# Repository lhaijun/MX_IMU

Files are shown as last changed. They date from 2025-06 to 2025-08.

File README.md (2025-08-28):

1. 代码优化：更合理稳定的代码组织结构为了优化数据读取、姿态解算和串口发送的代码结构，同时提升稳定性和可维护性，建议从以下几个方面入手：1.1 任务划分与优先级设计目前你使用 FreeRTOS 的定时器轮询方式，虽然简单，但可能导致任务耦合过高，且实时性难以保证。建议将功能模块拆分为独立的任务，利用 FreeRTOS 的多任务特性来提升代码模块化和稳定性。任务拆分建议：IMU 数据读取任务（高优先级）：负责从 ICM42688P 读取原始数据（加速度、角速度等）。建议使用 SPI/I2C 中断驱动的方式，避免轮询占用 CPU。读取频率可以根据 IMU 的采样率（如 100Hz 或 200Hz）设置。
姿态解算任务（中优先级）：接收 IMU 原始数据，进行姿态解算（如四元数或欧拉角）。可以利用 FreeRTOS 的队列（Queue）或信号量（Semaphore）从 IMU 任务获取数据，避免直接调用。
数据发送任务（低优先级）：负责将解算结果通过串口（UART）以 MAVLink 协议发送到上位机。可以使用另一队列接收姿态解算任务的数据。
命令处理任务（低优先级）：处理上位机通过 MAVLink 协议发送的参数调整命令，更新板载配置。

优先级设置：IMU 读取任务优先级最高，确保数据采集的实时性。
姿态解算次之，保证解算的及时性。
数据发送和命令处理优先级较低，因为串口通信和参数调整对实时性要求较低。

任务通信：使用 FreeRTOS 的 队列（Queue） 传递数据，例如：IMU 任务将原始数据放入队列，姿态解算任务从中读取。
姿态解算任务将结果放入另一个队列，供数据发送任务使用。

如果需要同步，使用 信号量（Semaphore） 或 事件标志（Event Group） 通知任务间状态。

1.2 替换定时器轮询为中断驱动IMU 数据读取：ICM42688P 支持数据就绪中断（Data Ready Interrupt）。建议配置中断引脚，当 IMU 数据准备好时触发中断，在中断服务函数（ISR）中读取数据并存入队列。这样可以避免轮询浪费 CPU 资源。
串口发送：使用 UART 的 DMA 模式发送 MAVLink 数据包，减少 CPU 干预。FreeRTOS 的任务只需将数据写入 DMA 缓冲区，硬件会自动完成发送。
姿态解算：姿态解算任务可以由事件触发（如队列中有新数据时运行），避免固定周期轮询。

1.3 代码模块化分离硬件驱动与应用逻辑：将 ICM42688P 的 SPI/I2C 驱动代码封装为独立模块（如 icm42688p.c/h），提供初始化、数据读取等接口。
姿态解算算法（如 Madgwick 或 Mahony 滤波）封装为单独模块（如 attitude.c/h），输入为 IMU 数据，输出为姿态数据。
MAVLink 协议处理封装为单独模块（如 mavlink_handler.c/h），负责打包和解析数据。

配置文件：将关键参数（如 IMU 采样率、滤波参数、串口波特率）集中在一个配置文件（如 config.h）中，方便上位机调整和代码维护。
错误处理：为每个模块添加错误检测和日志记录（如通过串口输出调试信息），便于调试和排查问题。

1.4 优化 FreeRTOS 资源使用任务栈大小：使用 FreeRTOS 的 uxTaskGetStackHighWaterMark 检查每个任务的栈使用情况，调整栈大小以节省内存。
队列长度：根据数据速率和任务调度频率，合理设置队列长度，避免队列满导致数据丢失。
调度器优化：确保任务调度频率与硬件性能匹配，避免任务抢占导致延迟。例如，IMU 采样率 100Hz，任务调度周期应与之同步。

1.5 示例代码结构以下是一个推荐的 FreeRTOS 任务组织示例：c

#include "FreeRTOS.h"
#include "task.h"
#include "queue.h"
#include "icm42688p.h"
#include "attitude.h"
#include "mavlink_handler.h"

// 队列句柄
QueueHandle_t imu_data_queue, attitude_data_queue;

// IMU 数据读取任务
void imu_read_task(void *pvParameters) {
    while (1) {
        // 假设通过中断触发读取
        imu_data_t data = icm42688p_read();
        xQueueSend(imu_data_queue, &data, portMAX_DELAY);
        vTaskDelay(pdMS_TO_TICKS(10)); // 100Hz
    }
}

// 姿态解算任务
void attitude_task(void *pvParameters) {
    imu_data_t imu_data;
    attitude_data_t attitude;
    while (1) {
        if (xQueueReceive(imu_data_queue, &imu_data, portMAX_DELAY)) {
            attitude = attitude_calculate(&imu_data);
            xQueueSend(attitude_data_queue, &attitude, portMAX_DELAY);
        }
    }
}

// 数据发送任务
void mavlink_send_task(void *pvParameters) {
    attitude_data_t attitude;
    while (1) {
        if (xQueueReceive(attitude_data_queue, &attitude, portMAX_DELAY)) {
            mavlink_send_attitude(&attitude);
        }
    }
}

void main(void) {
    // 初始化硬件和 FreeRTOS
    icm42688p_init();
    mavlink_init();
    
    // 创建队列
    imu_data_queue = xQueueCreate(10, sizeof(imu_data_t));
    attitude_data_queue = xQueueCreate(10, sizeof(attitude_data_t));
    
    // 创建任务
    xTaskCreate(imu_read_task, "IMU", 256, NULL, 3, NULL);
    xTaskCreate(attitude_task, "Attitude", 512, NULL, 2, NULL);
    xTaskCreate(mavlink_send_task, "MAVLink", 256, NULL, 1, NULL);
    
    // 启动调度器
    vTaskStartScheduler();
}

1.6 性能测试与验证实时性测试：使用逻辑分析仪或调试串口记录任务执行时间，确保 IMU 数据读取和姿态解算满足实时性要求。
稳定性测试：长时间运行系统，检查是否有内存泄漏或任务死锁。
数据一致性：验证上位机接收的 MAVLink 数据与板载解算结果一致。

2. 开源文档组织：GitHub 开源准备为了在 GitHub 上开源你的设计和代码，清晰的文档和项目结构是吸引用户和贡献者的关键。以下是建议的文档组织方式和内容：2.1 仓库结构

project_name/
├── docs/                     # 文档目录
│   ├── hardware/             # 硬件相关文档
│   ├── software/             # 软件相关文档
│   └── tutorials/            # 使用教程
├── firmware/                 # 固件代码
│   ├── src/                  # 源代码
│   ├── inc/                  # 头文件
│   └── lib/                  # 第三方库（如 FreeRTOS、MAVLink）
├── hardware/                 # 硬件设计文件
│   ├── schematic/            # 原理图（如 KiCad 文件）
│   ├── pcb/                  # PCB 布局
│   └── bom/                  # 物料清单
├── examples/                 # 示例代码或上位机代码
├── LICENSE                   # 开源许可证（如 MIT、Apache 2.0）
└── README.md                 # 项目主页

2.2 README.md 内容README 是项目的门面，需简洁但信息全面。建议包含以下内容：项目概述：简要介绍项目（STM32F405 + ICM42688P 的 IMU 系统，支持 MAVLink 协议）。
功能特性：IMU 数据读取（加速度、角速度）
姿态解算（四元数/欧拉角）
MAVLink 协议通信
FreeRTOS 实时系统

硬件要求：列出核心硬件（STM32F405、ICM42688P）及其连接方式。
软件依赖：STM32CubeIDE 或其他 IDE
FreeRTOS
MAVLink 库

快速开始：克隆仓库：git clone <repo_url>
硬件连接说明
编译和烧录固件步骤
上位机配置和运行

贡献指南：如何提交 Issue 或 Pull Request。
许可证：明确项目的开源许可证。
联系方式：可选，提供邮箱或社区链接。

2.3 文档内容硬件文档（docs/hardware/）：原理图和 PCB 设计说明（推荐使用 KiCad 或 Eagle）。
物料清单（BOM），包括元件型号和供应商链接。
硬件连接说明（如 SPI/I2C 引脚分配）。

软件文档（docs/software/）：代码架构说明（任务划分、模块功能）。
MAVLink 协议实现细节（支持的消息类型、参数调整流程）。
姿态解算算法说明（如 Madgwick 滤波的原理和参数）。

使用教程（docs/tutorials/）：固件烧录教程（使用 ST-Link 或其他工具）。
上位机配置和运行说明。
参数调整示例（如通过 MAVLink 修改滤波增益）。

API 文档（可选）：如果代码模块化程度高，可使用 Doxygen 生成 API 文档。

2.4 开源注意事项选择许可证：推荐 MIT 或 Apache 2.0，简单且适合硬件/软件开源。确保在仓库根目录添加 LICENSE 文件。
代码注释：确保代码有清晰的注释，尤其是关键模块（如 IMU 驱动、姿态解算）。
版本管理：使用 Git 提交规范（如 feat: add IMU driver），并定期发布版本（Releases）。
测试用例：提供简单的测试代码或脚本，帮助用户验证硬件和固件功能。
社区互动：在 README 中添加 GitHub Issues 模板，鼓励用户反馈问题或贡献代码。

2.5 示例 README 片段markdown

# STM32F405 + ICM42688P IMU Project

A FreeRTOS-based IMU system using STM32F405 and ICM42688P, with MAVLink protocol support for attitude calculation and data communication.

## Features
- High-frequency IMU data acquisition (100Hz+)
- Real-time attitude calculation (quaternion/Euler angles)
- MAVLink protocol for PC communication
- Configurable parameters via MAVLink

## Getting Started
1. Clone the repository:
   ```bash
   git clone https://github.com/yourusername/project_name

Connect STM32F405 and ICM42688P via SPI/I2C (see docs/hardware/).
Build and flash firmware using STM32CubeIDE.
Run the provided PC application to receive MAVLink data.

LicenseMIT License

---

### 3. 其他建议
- **硬件优化**：
  - 检查 ICM42688P 的电源和信号完整性，确保数据读取稳定。
  - 如果可能，添加外部晶振以提高 STM32F405 的时钟精度。
- **上位机完善**：
  - 在上位机中添加数据可视化功能（如姿态 3D 模型）。
  - 提供 MAVLink 参数调整的 GUI 界面，方便用户操作。
- **开源社区推广**：
  - 在 X 或其他技术社区分享你的项目，吸引开发者参与。
  - 考虑制作一个简单的演示视频，展示硬件运行效果。

---

### 总结
- **代码优化**：将功能拆分为 FreeRTOS 任务（IMU 读取、姿态解算、数据发送），使用中断驱动和队列通信，模块化代码结构。
- **文档组织**：在 GitHub 上创建清晰的目录结构，编写详细的 README 和模块化文档，选择合适的许可证。

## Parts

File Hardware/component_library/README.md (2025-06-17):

# component_library

KiCad component library.

---

<details markdown="1">
  <summary>Table of Contents</summary>

<!-- TOC -->
* [component_library](#componentlibrary)
  * [1 Overview](#1-overview)
  * [2 Symbol Conventions](#2-symbol-conventions)
    * [2.1 General Properties](#21-general-properties)
    * [2.2 Simulation Model](#22-simulation-model)
  * [3 Footprint Conventions](#3-footprint-conventions)
    * [3.1 General Properties](#31-general-properties)
    * [3.2 Clearance Overrides and Settings](#32-clearance-overrides-and-settings)
    * [3.3 3D Models](#33-3d-models)
  * [4 Automations (GitHub Actions)](#4-automations-github-actions)
<!-- TOC -->

</details>

---

## 1 Overview

This repo stores all KiCad component related files (symbols, footprints, 3d
models, etc.). Conventions are listed below.

---

## 2 Symbol Conventions

### 2.1 General Properties

| n  | Name | Explained | Show | KiCad Default |
|----|---|---|---|---|
| 1  | `Reference` | Symbol reference (REQUIRED)  | Yes  | Yes |
| 2  | `Value` | Value, if applicable | Yes  | Yes |
| 3  | `Footprint` | Location from repo root dir  | No | Yes |
| 4  | `Datasheet` | URL/location of datasheet | No | Yes |
| 5  | `Description` | Short 1 sentence description | No | Yes |
| 6  | `Manufacturer` | Fab/manufacturer name | No | No |
| 7  | `Manufacturer Part Number` | Must match if added! | No | No |
| 8  | `Distributor` | Supplier/distributor name | No | No |
| 9  | `Distributor Part Number`  | Must match if added! | No | No |
| 10 | `Distributor Link` | URL to product purchase page | No | No |

### 2.2 Simulation Model

Add simulation SPICE models for reasonable components as needed. Complete when
the benefit of an accurate SPICE model outweighs the required effort.

---

## 3 Footprint Conventions

### 3.1 General Properties

| n | Name | Explained | Show | Layer | KiCad Default |
|---|---|---|---|---|---|
| 1 | `Reference` | Footprint reference (REQUIRED) | Yes  | F.Silkscreen | Yes |
| 2 | `Value` | Value, if applicable | Yes  | F.Fab | Yes |
| 3 | `Footprint` | Location from repo root dir | No | No show | Yes |
| 4 | `Datasheet` | URL/location of datasheet | No | No show | Yes |
| 5 | `Description` | Short 1 sentence description | No | No show | Yes |
| 6 | `Manufacturer` | Fab/manufacturer name | No | No show | No |
| 7 | `Manufacturer Part Number` | Must match if added! | No | No show | No |

### 3.2 Clearance Overrides and Settings

All optional, follow manufacturer recommendations.

### 3.3 3D Models

Always add a module unless there is none (PCB only footprint).

---

## 4 Automations (GitHub Actions)

GitHub actions pipelines are used to verify component information and supply
chain using distributor APIs.

The following distributors are currently supported:

1. DigiKey
2. Mouser

Distributor API supply chain checker workflows are saved
in [distributor_apis](docs/workflows/distributor_apis) for reference.

- Discontinued due to limited development and unnecessary slowdown in the
  current development process.

The badge markdown would be as follows:

```
![black_formatter](https://github.com/danielljeon/component_library/actions/workflows/black_formatter.yaml/badge.svg)
![distributor_apis](https://github.com/danielljeon/component_library/actions/workflows/distributor_apis.yaml/badge.svg)
```

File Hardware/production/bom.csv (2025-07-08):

Designator | Footprint | Quantity | Value | LCSC Part #
C1 | 0402 | 1 | 0.1u
C10 | 0402 | 1 | 10n
C2, C201, C202, C203, C204, C205, C400 | 0402 | 7 | 100n | C1525
C200 | 0603 | 1 | 4u7 | C19666
C206 | 0402 | 1 | 1u | C52923
C207 | 0402 | 1 | 10n | C15195
C208, C209, C4, C5 | 0603 | 4 | 2u2 | C23630
C210, C211 | 0402 | 2 | 12p | C1547
C3 | 0603 | 1 | 1u
C31 | 0603 | 1 | 4n7
D3, D4, D5 | 0402 | 3 | LED
FB200 | 0805 | 1 | 600 @ 600 MHz | C1017
J1, J2 | PinHeader_1x04_P1.27mm_Vertical | 2 | KH-1.27PH180-1X4P-L7.2
J3 | molex_2171750001_usb_c_6p | 1 | 2171750001
J4 | CONN-HEADER-VERT-5POS-2.54MM | 1 | ZX-PZ2.54-1-5PZZ
R1, R2 | 0603 | 2 | 5k1
R13, R14, R29 | 0402 | 3 | 330R
R19, R20 | 0603 | 2 | 60R
R200 | 0402 | 1 | 47 | C25118
R203 | 0402 | 1 | 10k | C25744
R23, R24 | 0805 | 2 | 1k5
R400, R401, R403, R406, R407 | 0402 | 5 | 22 | C25092
R9 | 0603 | 1 | 10k
SW1 | SW_SPST_B3U-3000P-B | 1 | SW_SPST
U1 | to-252-2_dpak-2-leg | 1 | ld39150dt33-r
U2 | PQFN50P300X250X97-14N | 1 | ICM-42688-P
U200 | LQFP-64_10x10mm_P0.5mm | 1 | STM32F405RGT6 | C15742
U4 | SOIC-8_3.9x4.9mm_P1.27mm | 1 | AT24C256 | C6482
U6 | sot96-1_soic-8 | 1 | TJA1051T/3
Y200 | Crystal_SMD_3225-4Pin_3.2x2.5mm | 1 | 16MHz | C13738

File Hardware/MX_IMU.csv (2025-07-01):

Reference | Qty | Value | DNP | Exclude from BOM | Exclude from Board | Footprint | Datasheet
C1 | 1 | 0.1u |  |  |  | Capacitor_SMD:C_0402_1005Metric | ~
C3 | 1 | 1u |  |  |  | Capacitor_SMD:C_0603_1608Metric | ~
C4,C7,C208,C209 | 4 | 2u2 |  |  |  | Capacitor_SMD:C_0603_1608Metric | ~
C10 | 1 | 10n |  |  |  | Capacitor_SMD:C_0201_0603Metric | ~
C29 | 1 | 100n |  |  |  | Capacitor_SMD:C_0603_1608Metric | ~
C31 | 1 | 4n7 |  |  |  | Capacitor_SMD:C_0603_1608Metric | ~
C200 | 1 | 4u7 |  |  |  | Capacitor_SMD:C_0603_1608Metric | ~
C201,C202,C203,C204,C205,C400 | 6 | 100n |  |  |  | Capacitor_SMD:C_0402_1005Metric | ~
C206 | 1 | 1u |  |  |  | Capacitor_SMD:C_0402_1005Metric | ~
C207 | 1 | 10n |  |  |  | Capacitor_SMD:C_0402_1005Metric | ~
C210,C211 | 2 | 12p |  |  |  | Capacitor_SMD:C_0402_1005Metric | ~
D3,D4,D5 | 3 | LED |  |  |  | LED_SMD:LED_0402_1005Metric | ~
FB200 | 1 | 600 @ 600 MHz |  |  |  | Inductor_SMD:L_0805_2012Metric | ~
J1 | 1 | CAN |  |  |  | Connector_PinHeader_1.00mm:PinHeader_1x04_P1.00mm_Vertical_SMD_Pin1Right | ~
J2 | 1 | USART |  |  |  | Connector_PinHeader_1.00mm:PinHeader_1x04_P1.00mm_Vertical_SMD_Pin1Right | ~
J3 | 1 | 2171750001 |  |  |  | common:molex_2171750001_usb_c_6p | https://www.molex.com/en-us/products/part-detail/2171750001
J401 | 1 | SWD |  |  |  | Connector_PinHeader_1.27mm:PinHeader_2x05_P1.27mm_Vertical_SMD | ~
R1,R2 | 2 | 5k1 |  |  |  | Resistor_SMD:R_0603_1608Metric | ~
R9 | 1 | 10k |  |  |  | Resistor_SMD:R_0603_1608Metric | ~
R13,R14,R29 | 3 | 330R |  |  |  | Resistor_SMD:R_0402_1005Metric | ~
R19,R20 | 2 | 60R |  |  |  | Resistor_SMD:R_0603_1608Metric | ~
R23,R24 | 2 | 1k5 |  |  |  | Resistor_SMD:R_0805_2012Metric_Pad1.20x1.40mm_HandSolder | ~
R200 | 1 | 47 |  |  |  | Resistor_SMD:R_0402_1005Metric | ~
R203 | 1 | 10k |  |  |  | Resistor_SMD:R_0402_1005Metric | ~
R400,R401,R402,R403,R406,R407 | 6 | 22 |  |  |  | Resistor_SMD:R_0402_1005Metric | ~
SW1 | 1 | SW_SPST |  |  |  | Button_Switch_SMD:SW_SPST_B3U-3000P-B | ~
U1 | 1 | ld39150dt33-r |  |  |  | common:to-252-2_dpak-2-leg | https://www.st.com/resource/en/datasheet/ld39150.pdf
U2 | 1 | ICM-42688-P |  |  |  | ICM_42688_P:PQFN50P300X250X97-14N
U4 | 1 | AT24C256 |  |  |  | Package_SO:SOIC-8_3.9x4.9mm_P1.27mm | https://datasheet.lcsc.com/lcsc/2304140030_Microchip-Tech-AT24C256C-SSHL-T_C6482.pdf
U6 | 1 | TJA1051T/3 |  |  |  | nxp:sot96-1_soic-8 | https://www.nxp.com/docs/en/data-sheet/TJA1051.pdf
U200 | 1 | STM32F405RGT6 |  |  |  | Package_QFP:LQFP-64_10x10mm_P0.5mm | http://www.st.com/st-web-ui/static/active/en/resource/technical/document/datasheet/DM00037051.pdf
Y200 | 1 | 16MHz |  |  |  | Crystal:Crystal_SMD_3225-4Pin_3.2x2.5mm | ~

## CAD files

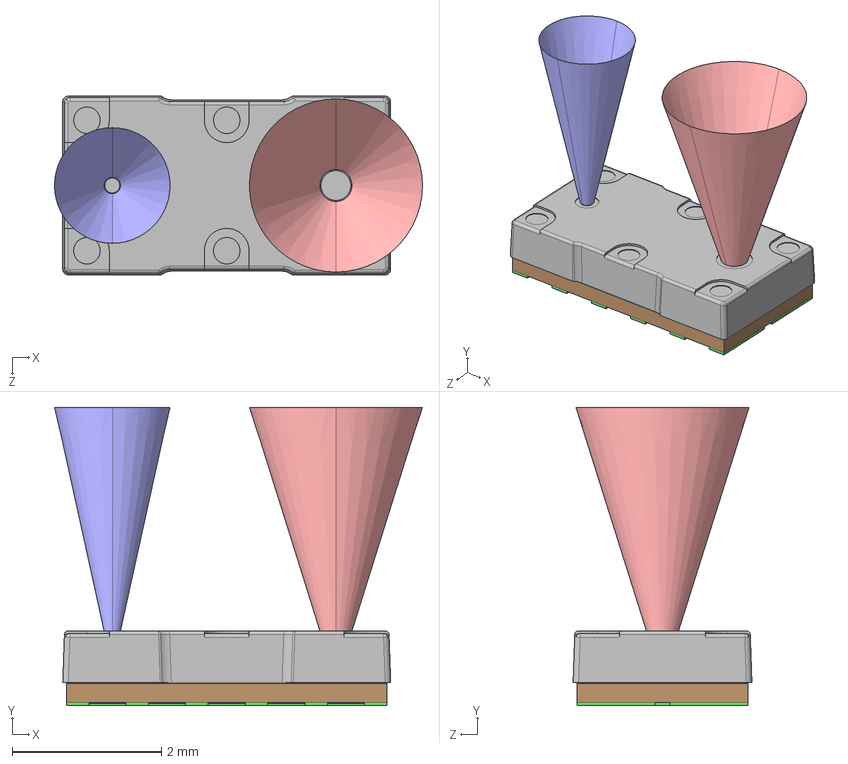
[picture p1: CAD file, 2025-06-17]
Hardware/component_library/model_3d/time_of_flight/VL53L3 MODULE ASSEMBLY.step
4.94 x 4.00 x 2.40 mm
VL53L3 Substrate
VL53L3 Cap
VL53L3 Tx Exclusion Cone
VL53L3 Rx Exclusion Cone

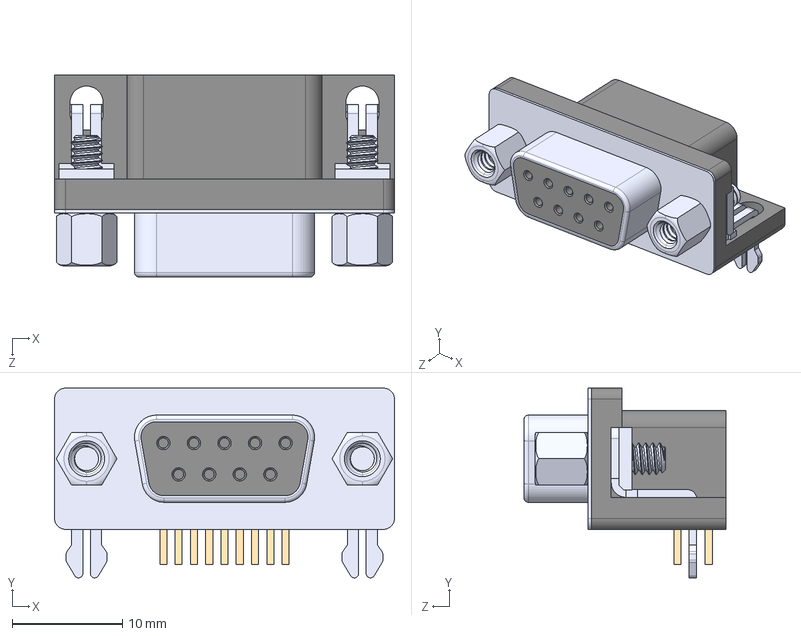
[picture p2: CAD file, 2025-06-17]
Hardware/component_library/A_DF_09_A_KG_T2S/A-DF_09_A_KG-T2S.step
30.8 x 17.2 x 18.3 mm

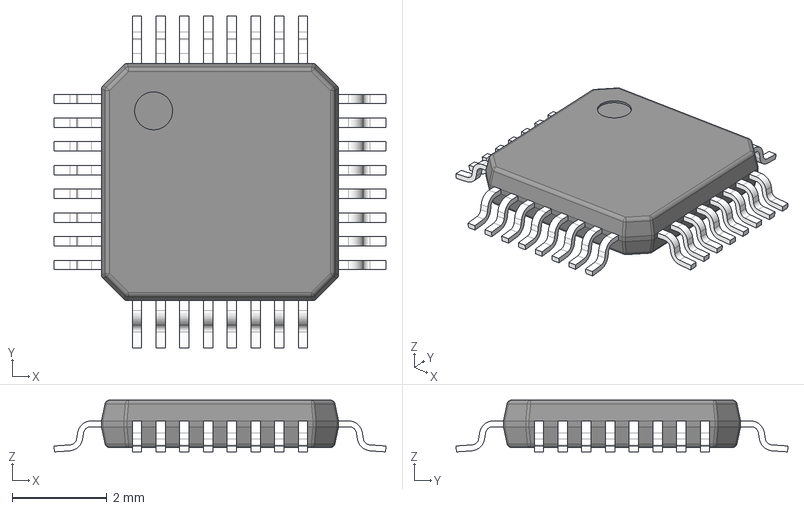
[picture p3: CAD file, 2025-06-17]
Hardware/component_library/model_3d/0_standard/TQFP-32.stp
7.00 x 7.00 x 1.09 mm
BODY-TQFP
LEAD-TQFP x 32
PIN1

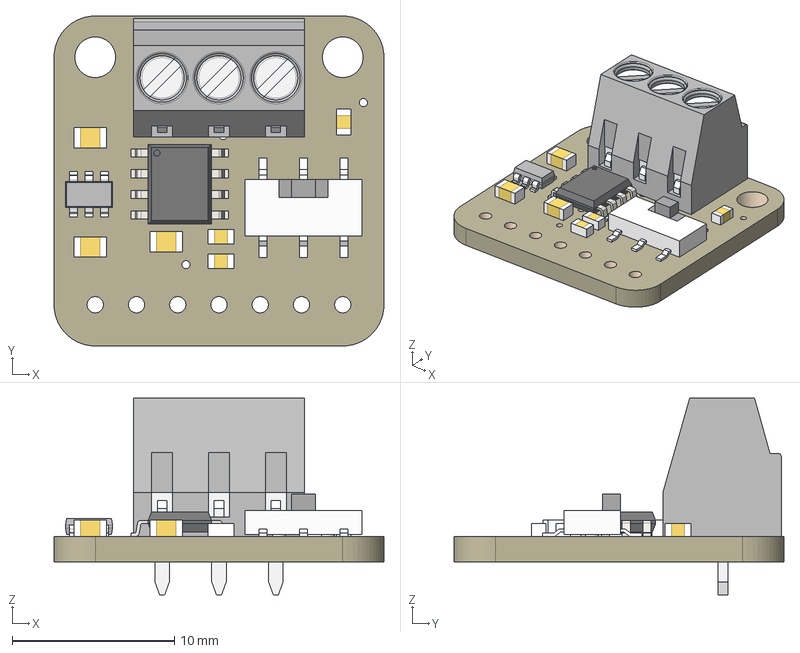
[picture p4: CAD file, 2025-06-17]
Hardware/component_library/model_3d/adafruit/5708 CAN Pal.step
20.3 x 20.3 x 12.1 mm
Board
TJA1051T/3
3.5mm Terminal
10uF x 2
AP3602
1uF
60 ohm x 3
EG1390

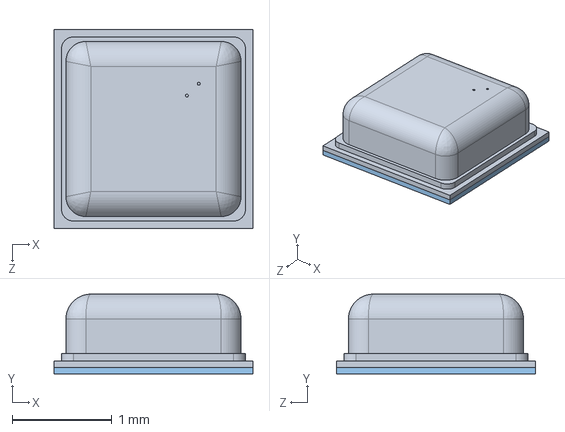
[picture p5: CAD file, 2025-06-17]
Hardware/component_library/model_3d/bosch/BMP581.step
2.00 x 0.801 x 2.00 mm

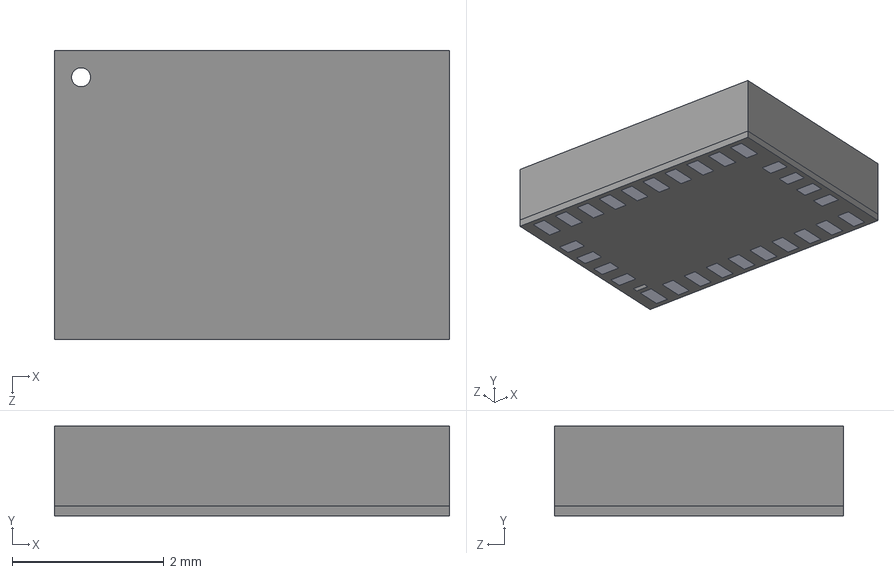
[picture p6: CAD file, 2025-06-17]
Hardware/component_library/model_3d/ceva/BNO085.stp
5.20 x 1.18 x 3.80 mm

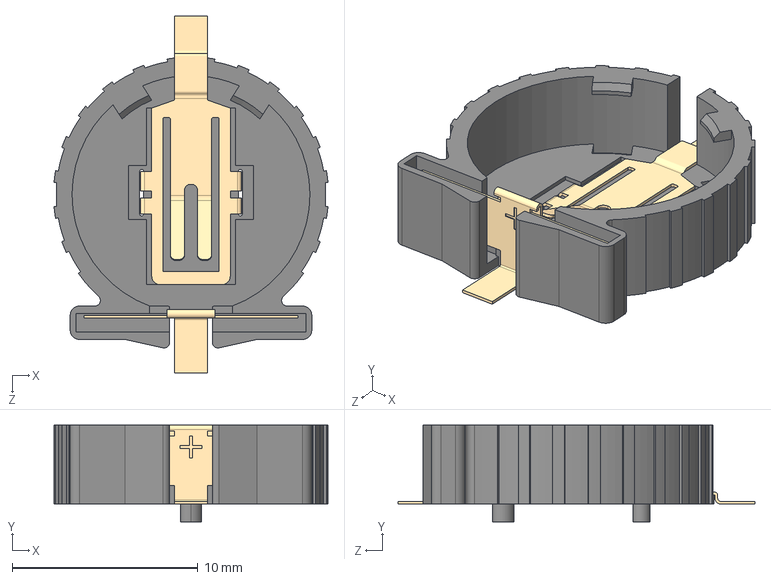
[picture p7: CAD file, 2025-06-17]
Hardware/component_library/model_3d/common/S8411-45R.step
14.7 x 5.20 x 19.2 mm

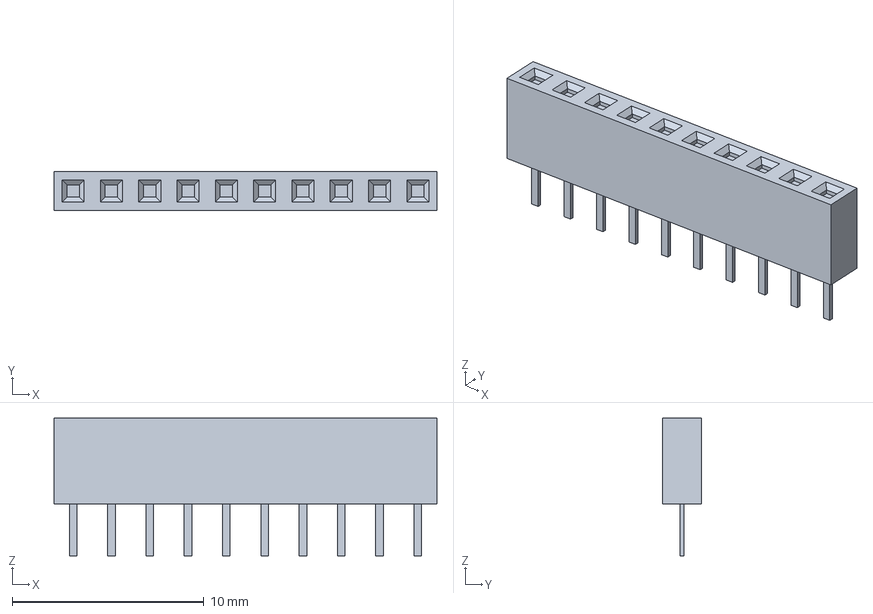
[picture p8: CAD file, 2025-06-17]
Hardware/component_library/model_3d/digi_xbee/c-1-2314876-0-a-3d.stp
20.0 x 2.06 x 7.20 mm

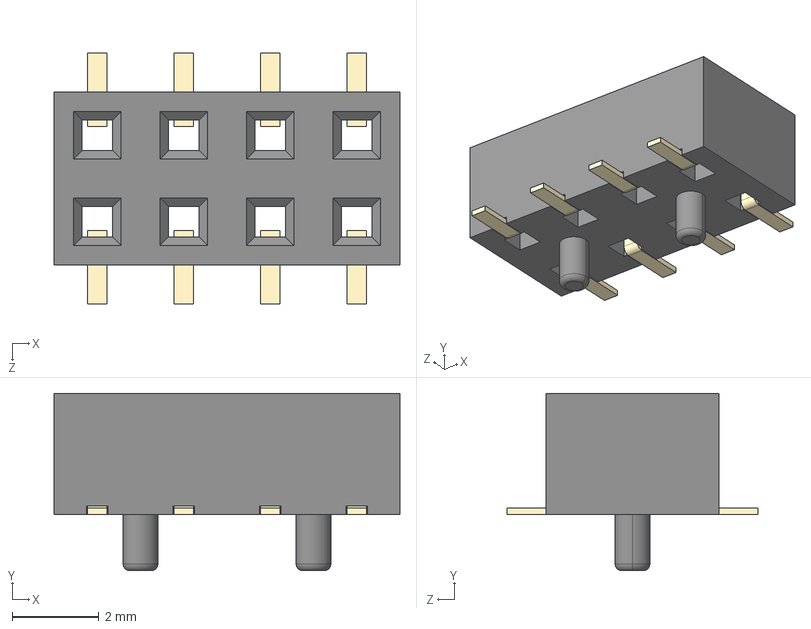
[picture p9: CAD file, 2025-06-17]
Hardware/component_library/model_3d/gct/BF080-08-A-1-L-C.STEP
8.00 x 4.10 x 5.80 mm
Pin gold x 4

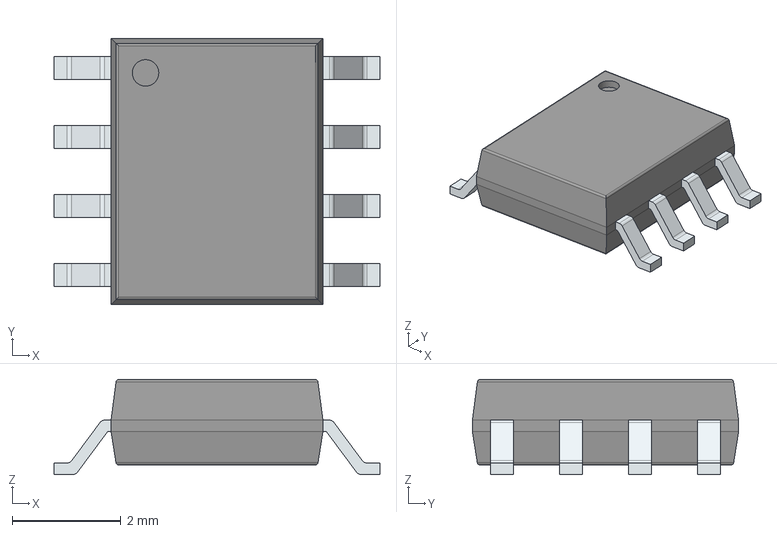
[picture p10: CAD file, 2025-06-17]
Hardware/component_library/model_3d/nxp/SOT96-1 SOIC-8.stp
6.00 x 4.90 x 1.75 mm
PinsArrayLR

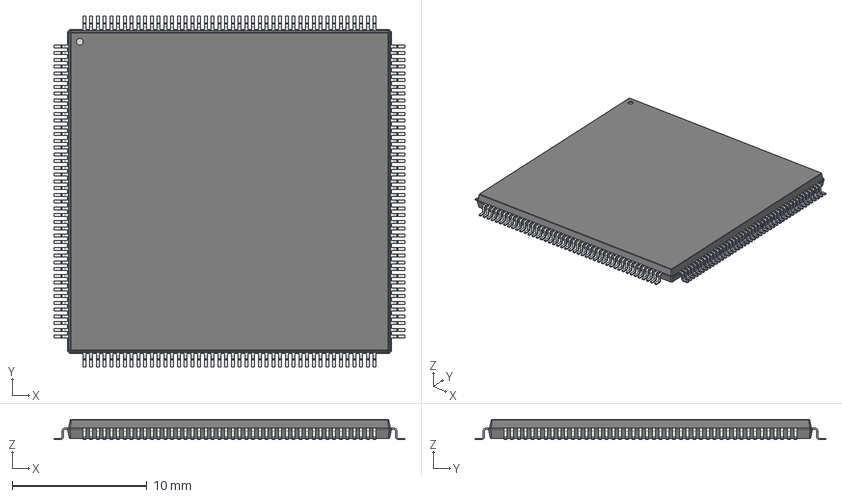
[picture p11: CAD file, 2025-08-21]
Hardware/component_library/model_3d/stm32f4/LQFP-176_24x24mm_P0.5mm.step
26.0 x 26.0 x 1.50 mm

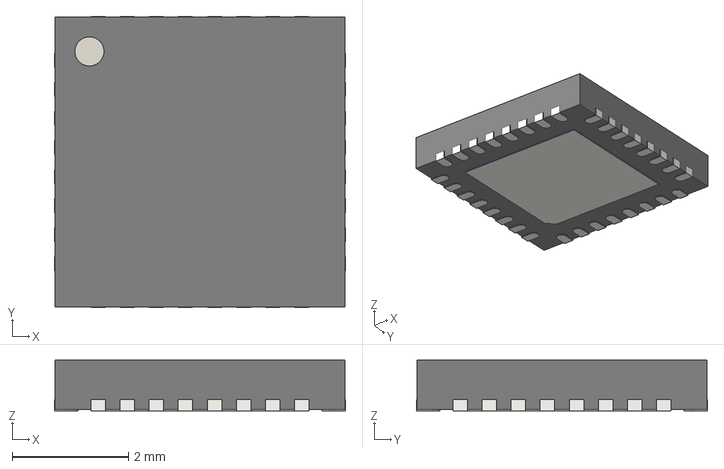
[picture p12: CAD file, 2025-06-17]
Hardware/component_library/model_3d/stm32l4/QFN-32-1EP_5x5mm_P0.5mm_EP3.3x3.3mm.step
5.00 x 5.00 x 0.875 mm

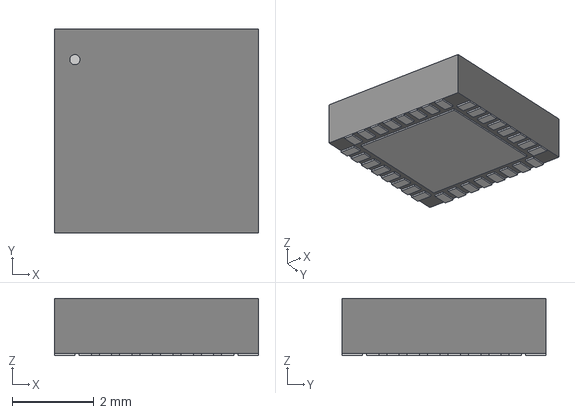
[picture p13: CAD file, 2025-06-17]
Hardware/component_library/model_3d/stm32wb0/VFQFPN-32_STM.step
5.00 x 5.00 x 1.40 mm

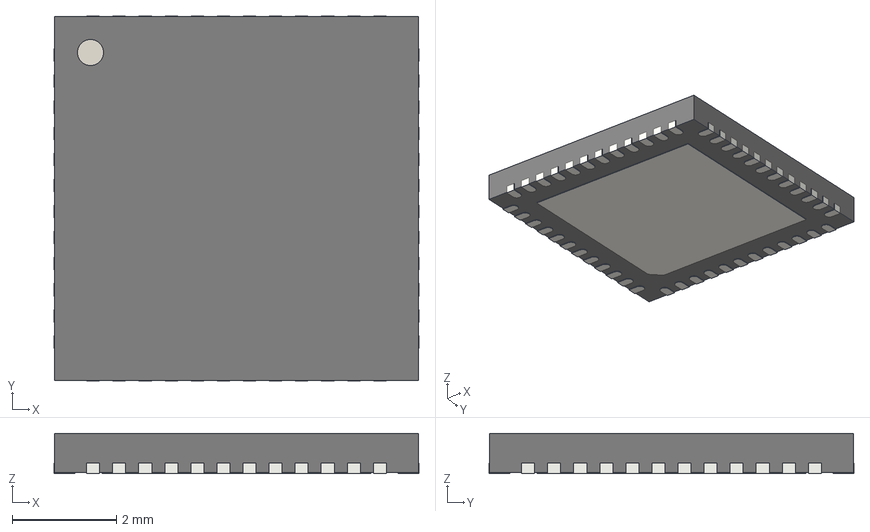
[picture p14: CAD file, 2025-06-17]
Hardware/component_library/model_3d/stm32wb5/QFN-48-1EP_7x7mm_P0.5mm_EP5.15x5.15mm.step
7.00 x 7.00 x 0.77 mm

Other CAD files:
Hardware/component_library/model_3d/switch/Same_Sky_TS04-66-55-BK-100-SMT.step
Hardware/component_library/model_3d/ti_buck/TPSM843x20.step
Hardware/component_library/model_3d/ublox/SAM_AP214.STEP
Hardware/component_library/RT9013-33GB.step
Hardware/component_library/PROG/705530039.stp
Hardware/component_library/model_3d/0_standard/SOT-23-THN.stp
Hardware/component_library/model_3d/adafruit/4682 Micro SD Breakout.step
Hardware/component_library/model_3d/adafruit/4754 BNO085 STEMMA QT.step
Hardware/component_library/model_3d/adafruit/4816 BMP390 QT.step
Hardware/component_library/model_3d/adafruit/5396 Adafruit VL53L4CD.step
Hardware/component_library/model_3d/common/2169900001.stp
Hardware/component_library/model_3d/common/2171750001.stp
Hardware/component_library/model_3d/common/472192001.stp
Hardware/component_library/model_3d/common/DLF162500LT-5028A1.STEP
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

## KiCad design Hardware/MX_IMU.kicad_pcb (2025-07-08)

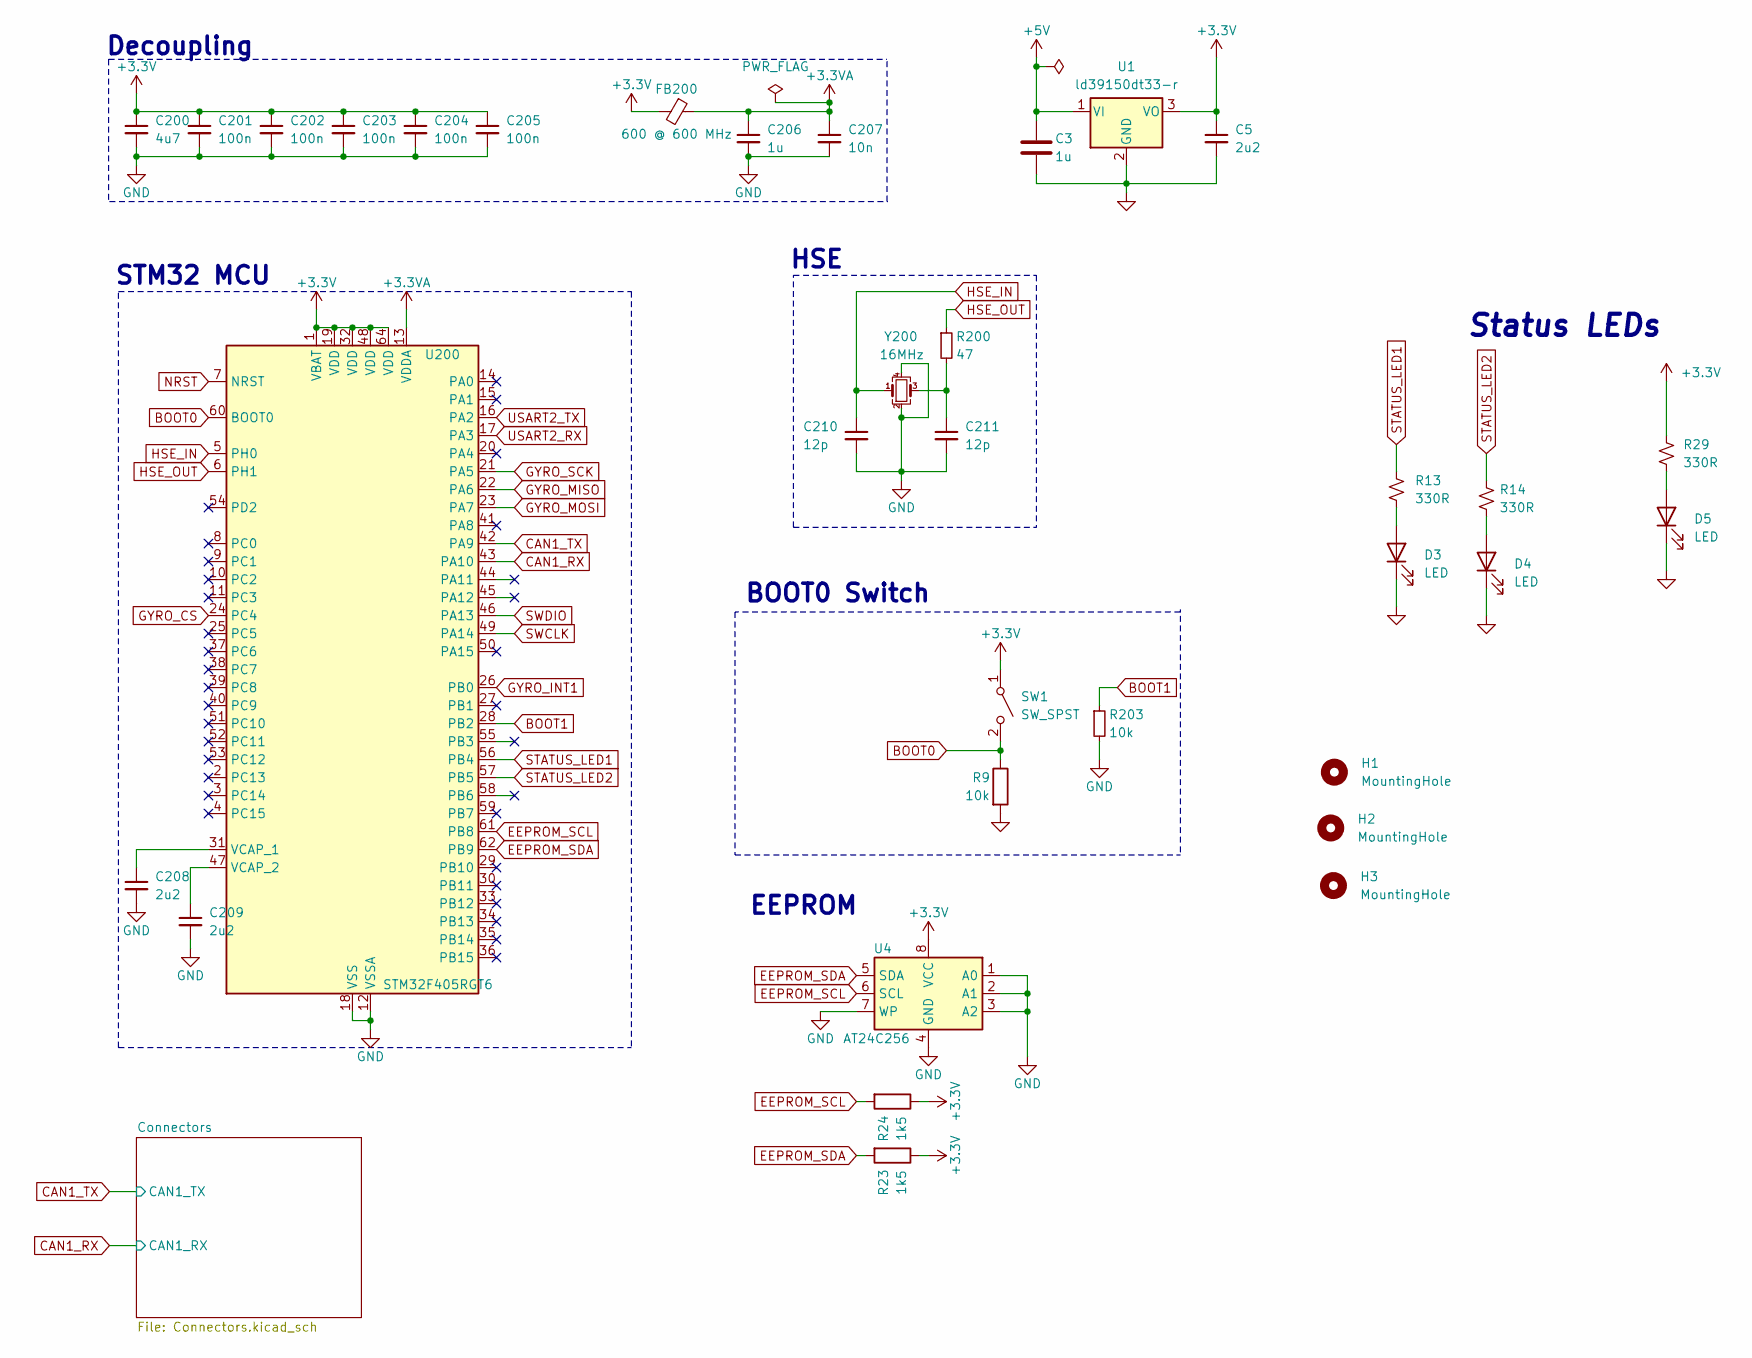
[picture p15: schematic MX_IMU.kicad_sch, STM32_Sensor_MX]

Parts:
C3: 1u; C_0603_1608Metric
C5, C208, C209: 2u2; C_0603_1608Metric; LCSC Part # C23630
C200: 4u7; C_0603_1608Metric; LCSC Part # C19666
C201, C202, C203, C204, C205: 100n; C_0402_1005Metric; LCSC Part # C1525
C206: 1u; C_0402_1005Metric; LCSC Part # C52923
C207: 10n; C_0402_1005Metric; LCSC Part # C15195
C210, C211: 12p; C_0402_1005Metric; LCSC Part # C1547
D3, D4, D5: LED; LED_0402_1005Metric
FB200: 600 @ 600 MHz; L_0805_2012Metric; LCSC Part # C1017
H1, H2, H3: MountingHole; MountingHole_2mm
R9: 10k; R_0603_1608Metric
R13, R14, R29: 330R; R_0402_1005Metric
R23, R24: 1k5; R_0805_2012Metric_Pad1.20x1.40mm_HandSolder
R200: 47; R_0402_1005Metric; LCSC Part # C25118
R203: 10k; R_0402_1005Metric; LCSC Part # C25744
SW1: SW_SPST; SW_SPST_B3U-3000P-B
U1: ld39150dt33-r; to-252-2_dpak-2-leg; Manufacturer Part Number LD39150DT33-R
U4: AT24C256; SOIC-8_3.9x4.9mm_P1.27mm; LCSC C6482
U200: STM32F405RGT6; LQFP-64_10x10mm_P0.5mm; LCSC Part # C15742
Y200: 16MHz; Crystal_SMD_3225-4Pin_3.2x2.5mm; LCSC Part # C13738

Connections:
+3.3V: C5.1, C200.1, C201.1, C202.1, C203.1, C204.1, C205.1, FB200.2, R23.1, R24.1, R29.1, SW1.1 (A), U1.3 (VO), U4.8 (VCC), U200.1 (VBAT), U200.19 (VDD), U200.32 (VDD), U200.48 (VDD), U200.64 (VDD); also elsewhere on the board
+3.3VA: C206.1, C207.1, FB200.1, U200.13 (VDDA)
+5V: C3.1, U1.1 (VI); also elsewhere on the board
BOOT0: R9.1, SW1.2 (B), U200.60 (BOOT0)
BOOT1: R203.1, U200.28 (PB2)
CAN1_RX: U200.43 (PA10); also elsewhere on the board
CAN1_TX: U200.42 (PA9); also elsewhere on the board
EEPROM_SCL: R24.2, U4.6 (SCL), U200.61 (PB8)
EEPROM_SDA: R23.2, U4.5 (SDA), U200.62 (PB9)
GND: C3.2, C5.2, C200.2, C201.2, C202.2, C203.2, C204.2, C205.2, C206.2, C207.2, C208.2, C209.2, C210.2, C211.2, D3.1 (K), D4.1 (K), D5.1 (K), R9.2, R203.2, U1.2 (GND), U4.1 (A0), U4.2 (A1), U4.3 (A2), U4.4 (GND), U4.7 (WP), U200.12 (VSSA), U200.18 (VSS), U200.63 (VSS), Y200.2, Y200.4; also elsewhere on the board
GYRO_CS: U200.24 (PC4); also elsewhere on the board
GYRO_INT1: U200.26 (PB0); also elsewhere on the board
GYRO_MISO: U200.22 (PA6); also elsewhere on the board
GYRO_MOSI: U200.23 (PA7); also elsewhere on the board
GYRO_SCK: U200.21 (PA5); also elsewhere on the board
HSE_IN: C210.1, U200.5 (PH0), Y200.1
HSE_OUT: R200.1, U200.6 (PH1)
NRST: U200.7 (NRST); also elsewhere on the board
unnamed: C211.1, R200.2, Y200.3
unnamed: D3.2 (A), R13.2
unnamed: D4.2 (A), R14.2
unnamed: D5.2 (A), R29.2
unnamed: C208.1, U200.31 (VCAP_1)
unnamed: C209.1, U200.47 (VCAP_2)
STATUS_LED1: R13.1, U200.56 (PB4)
STATUS_LED2: R14.1, U200.57 (PB5)
SWCLK: U200.49 (PA14); also elsewhere on the board
SWDIO: U200.46 (PA13); also elsewhere on the board
USART2_RX: U200.17 (PA3); also elsewhere on the board
USART2_TX: U200.16 (PA2); also elsewhere on the board

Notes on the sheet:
HSE
Status LEDs
STM32 MCU
BOOT0 Switch
EEPROM
Decoupling

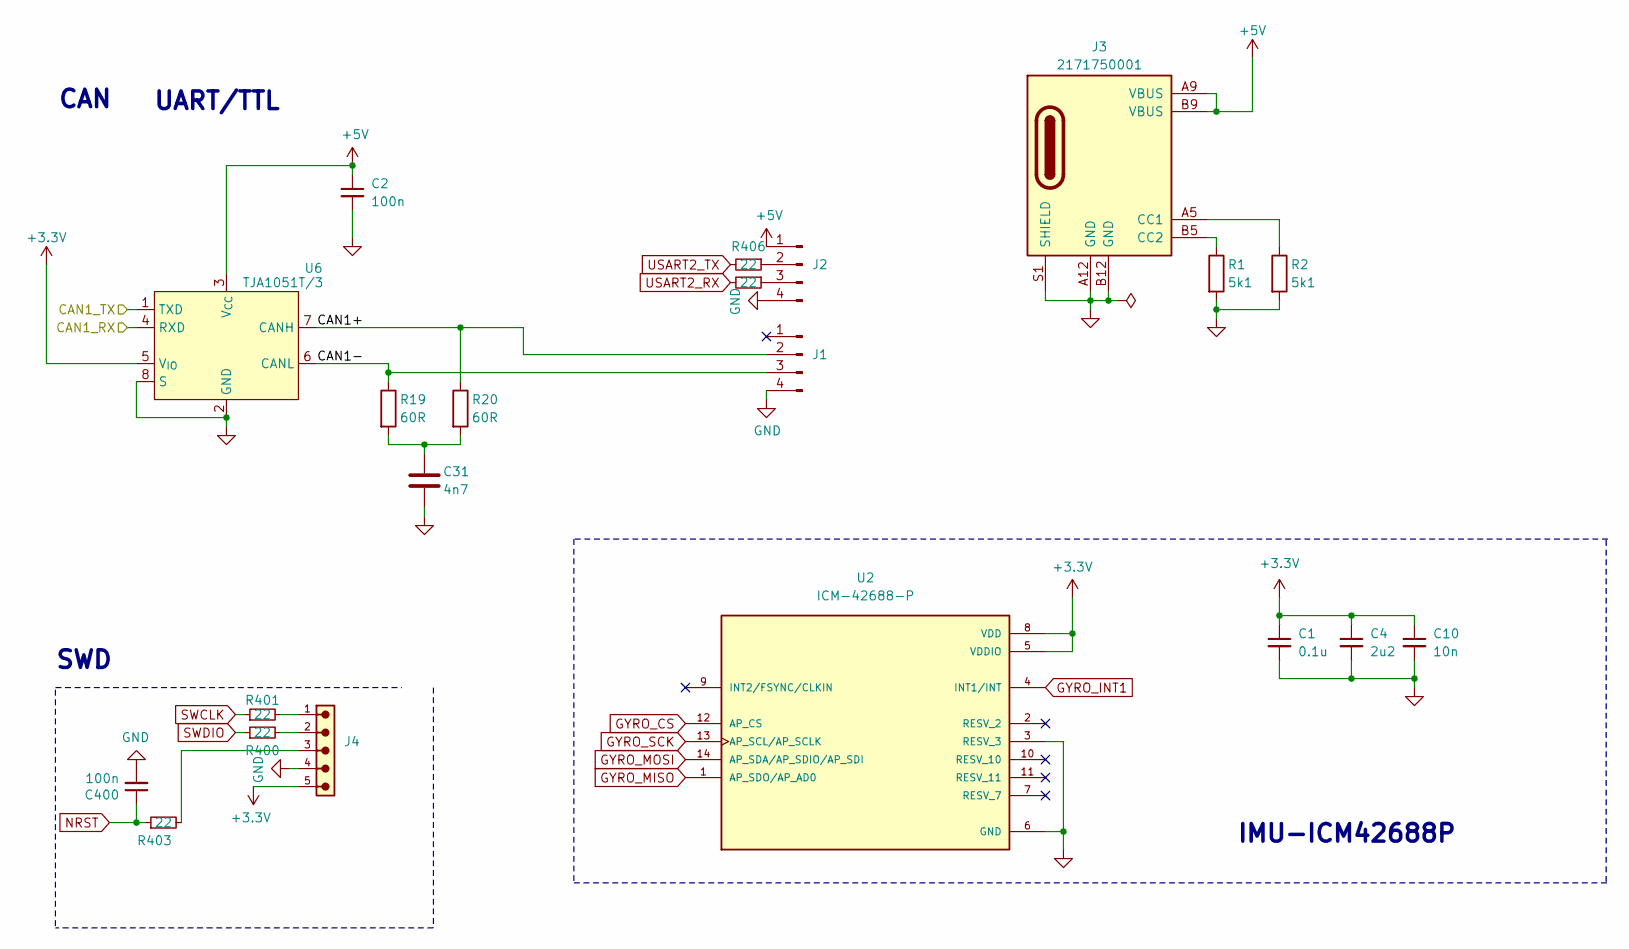
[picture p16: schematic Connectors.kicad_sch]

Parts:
C1: 0.1u; C_0402_1005Metric
C2, C400: 100n; C_0402_1005Metric; LCSC Part # C1525
C4: 2u2; C_0603_1608Metric; LCSC Part # C23630
C10: 10n; C_0402_1005Metric
C31: 4n7; C_0603_1608Metric
J1, J2: KH-1.27PH180-1X4P-L7.2; PinHeader_1x04_P1.27mm_Vertical
J3: 2171750001; molex_2171750001_usb_c_6p; Manufacturer Part Number 2171750001
J4: ZX-PZ2.54-1-5PZZ; CONN-HEADER-VERT-5POS-2.54MM
R1, R2: 5k1; R_0603_1608Metric
R19, R20: 60R; R_0603_1608Metric
R400, R401, R403, R406, R407: 22; R_0402_1005Metric; LCSC Part # C25092
U2: ICM-42688-P; PQFN50P300X250X97-14N; PARTREV 1.2
U6: TJA1051T/3; sot96-1_soic-8; Manufacturer Part Number TJA1051T/3

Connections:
+3.3V: C1.1, C4.1, C10.1, J4.5, U2.5 (VDDIO), U2.8 (VDD), U6.5 (V_{IO}); also elsewhere on the board
+5V: C2.1, J2.1, J3.A9 (VBUS), J3.B9 (VBUS), U6.3 (V_{CC}); also elsewhere on the board
/Connectors/CAN1+: J1.2, R20.1, U6.7 (CANH)
/Connectors/CAN1-: J1.3, R19.1, U6.6 (CANL)
CAN1_RX: U6.4 (RXD); also elsewhere on the board
CAN1_TX: U6.1 (TXD); also elsewhere on the board
GND: C1.2, C2.2, C4.2, C10.2, C31.2, C400.2, J1.4, J2.4, J3.A12 (GND), J3.B12 (GND), J3.S1 (SHIELD), J4.4, R1.2, R2.2, U2.3 (RESV_3), U2.6 (GND), U6.2 (GND), U6.8 (S); also elsewhere on the board
GYRO_CS: U2.12 (AP_CS); also elsewhere on the board
GYRO_INT1: U2.4 (INT1/INT); also elsewhere on the board
GYRO_MISO: U2.1 (AP_SDO/AP_AD0); also elsewhere on the board
GYRO_MOSI: U2.14 (AP_SDA/AP_SDIO/AP_SDI); also elsewhere on the board
GYRO_SCK: U2.13 (AP_SCL/AP_SCLK); also elsewhere on the board
NRST: C400.1, R403.1; also elsewhere on the board
unnamed: C31.1, R19.2, R20.2
unnamed: J2.2, R406.1
unnamed: J2.3, R407.1
unnamed: J3.A5 (CC1), R2.1
unnamed: J3.B5 (CC2), R1.1
unnamed: J4.1, R401.2
unnamed: J4.2, R400.2
unnamed: J4.3, R403.2
SWCLK: R401.1; also elsewhere on the board
SWDIO: R400.1; also elsewhere on the board
USART2_RX: R407.2; also elsewhere on the board
USART2_TX: R406.2; also elsewhere on the board

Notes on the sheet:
SWD
IMU-ICM42688P
CAN
UART/TTL

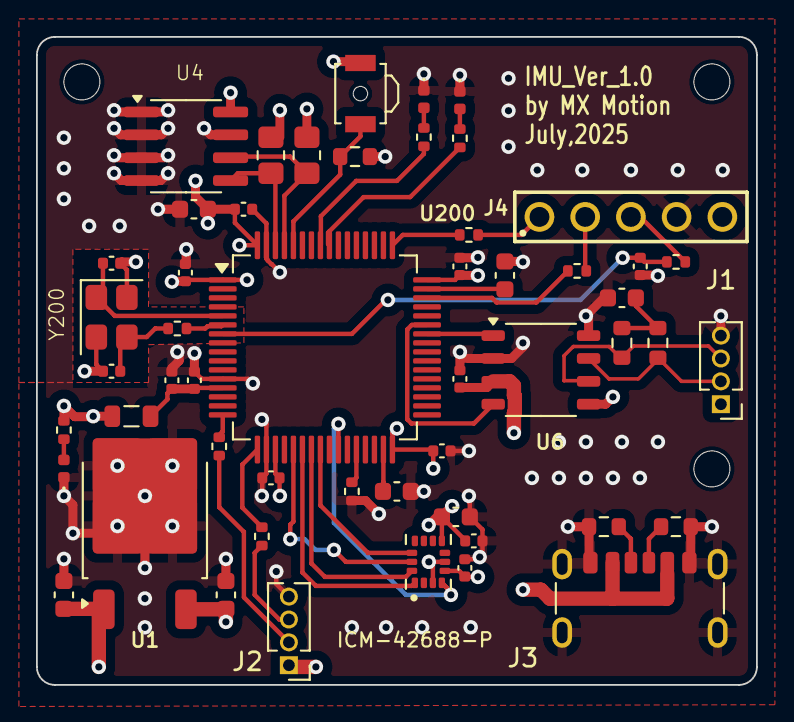
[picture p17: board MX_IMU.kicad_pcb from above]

Board: 4 copper layers, 40.0 x 36.0 mm, 55 parts (0 on the bottom side), 40 nets.

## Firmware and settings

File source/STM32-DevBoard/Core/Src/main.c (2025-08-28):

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
/* Includes ------------------------------------------------------------------*/
#include "main.h"
#include "cmsis_os.h"

/* USER CODE BEGIN Includes */
#include "icm42688p.h"
#include <common/mavlink.h>
#include "Fusion.h"
#include "time.h"
/* USER CODE END Includes */

/* USER CODE BEGIN PTD */
	// Define calibration (replace with actual calibration data if available)
	    const FusionMatrix gyroscopeMisalignment = {1.0f, 0.0f, 0.0f, 0.0f, 1.0f, 0.0f, 0.0f, 0.0f, 1.0f};
	    const FusionVector gyroscopeSensitivity = {1.0f, 1.0f, 1.0f};
	    const FusionVector gyroscopeOffset = {0.0f, 0.0f, 0.0f};
	    const FusionMatrix accelerometerMisalignment = {1.0f, 0.0f, 0.0f, 0.0f, 1.0f, 0.0f, 0.0f, 0.0f, 1.0f};
	    const FusionVector accelerometerSensitivity = {1.0f, 1.0f, 1.0f};
	    const FusionVector accelerometerOffset = {0.0f, 0.0f, 0.0f};
	    const FusionMatrix softIronMatrix = {1.0f, 0.0f, 0.0f, 0.0f, 1.0f, 0.0f, 0.0f, 0.0f, 1.0f};
	    const FusionVector hardIronOffset = {0.0f, 0.0f, 0.0f};
/* USER CODE END PTD */

/* USER CODE BEGIN PD */
ICM42688P_Data_t imudata;
#define IMU_DATA_SIZE 20 // 更新为 20 // Updated to 20
uint8_t imu_data_buffer[2][IMU_DATA_SIZE];
volatile uint8_t current_buffer_index = 0;
#define SAMPLE_RATE (100) // replace this with actual sample rate

// Initialise algorithms
FusionOffset offset;
FusionAhrs ahrs;
FusionEuler euler;

void GetPose(void);

/* USER CODE BEGIN PV */
uint8_t tx_data[] = "Hello from STM32 via DMA!\r\n";
uint8_t mavlink_tx_buffer[MAVLINK_MAX_PACKET_LEN];

/* USER CODE END PV */
/* USER CODE END PD */

CRC_HandleTypeDef hcrc;

SPI_HandleTypeDef hspi1;
DMA_HandleTypeDef hdma_spi1_rx;

TIM_HandleTypeDef htim1;
TIM_HandleTypeDef htim2;

UART_HandleTypeDef huart1;
UART_HandleTypeDef huart2;
DMA_HandleTypeDef hdma_usart2_rx;
DMA_HandleTypeDef hdma_usart2_tx;

/* Definitions for defaultTask */
osThreadId_t defaultTaskHandle;
const osThreadAttr_t defaultTask_attributes = {
  .name = "defaultTask",
  .stack_size = 2048,
  .priority = (osPriority_t) osPriorityNormal,
};
/* Definitions for imu_acquisition */
osThreadId_t imu_acquisitionHandle;
const osThreadAttr_t imu_acquisition_attributes = {
  .name = "imu_acquisition",
  .stack_size = 128 * 4,
  .priority = (osPriority_t) osPriorityHigh,
};
/* Definitions for pose_estimation */
osThreadId_t pose_estimationHandle;
const osThreadAttr_t pose_estimation_attributes = {
  .name = "pose_estimation",
  .stack_size = 128 * 4,
  .priority = (osPriority_t) osPriorityNormal,
};
/* Definitions for uart_send */
osThreadId_t uart_sendHandle;
const osThreadAttr_t uart_send_attributes = {
  .name = "uart_send",
  .stack_size = 128 * 4,
  .priority = (osPriority_t) osPriorityLow,
};
void SystemClock_Config(void);
static void MX_GPIO_Init(void);
static void MX_DMA_Init(void);
static void MX_SPI1_Init(void);
static void MX_USART1_UART_Init(void);
static void MX_USART2_UART_Init(void);
static void MX_CRC_Init(void);
static void MX_TIM1_Init(void);
static void MX_TIM2_Init(void);
void StartDefaultTask(void *argument);
void StartIMUTask(void *argument);
void StartPose(void *argument);
void StartSend(void *argument);

/* USER CODE BEGIN 0 */
uint32_t preCNT = 0;
uint32_t delCNT = 0;
uint32_t GetTimeUS_TIM(void);
// Interrupt-specific configuration

/* USER CODE END 0 */

/**
  * @brief  The application entry point.
  * @retval int
  */
int main(void)
{

  /* MCU Configuration--------------------------------------------------------*/

  /* Reset of all peripherals, Initializes the Flash interface and the Systick. */
  HAL_Init();

  /* Configure the system clock */
  SystemClock_Config();

  /* Initialize all configured peripherals */
  MX_GPIO_Init();
  MX_DMA_Init();
  MX_SPI1_Init();
  MX_USART1_UART_Init();
  MX_USART2_UART_Init();
  MX_CRC_Init();
  MX_TIM1_Init();
  MX_TIM2_Init();
  /* USER CODE BEGIN 2 */
  HAL_TIM_Base_Start_IT(&htim1);
  HAL_TIM_Base_Start(&htim2);

  // Initialize ICM42688P driver
  // 初始化ICM42688P驱动
  ICM42688P_Init();


  FusionOffsetInitialise(&offset, SAMPLE_RATE);
  FusionAhrsInitialise(&ahrs);

  // Set AHRS algorithm settings
  const FusionAhrsSettings settings = {
          .convention = FusionConventionNwu,
          .gain = 0.5f,
          .gyroscopeRange = 2000.0f, /* replace this with actual gyroscope range in degrees/s */
          .accelerationRejection = 10.0f,
          .magneticRejection = 10.0f,
          .recoveryTriggerPeriod = 5 * SAMPLE_RATE, /* 5 seconds */
  };
  FusionAhrsSetSettings(&ahrs, &settings);
  /* USER CODE END 2 */

  /* Init scheduler */
  osKernelInitialize();

  /* USER CODE BEGIN RTOS_MUTEX */
  /* add mutexes, ... */
  /* USER CODE END RTOS_MUTEX */

  /* USER CODE BEGIN RTOS_SEMAPHORES */
  /* add semaphores, ... */
  /* USER CODE END RTOS_SEMAPHORES */

  /* USER CODE BEGIN RTOS_TIMERS */
  /* start timers, add new ones, ... */
  /* USER CODE END RTOS_TIMERS */

  /* USER CODE BEGIN RTOS_QUEUES */
  /* add queues, ... */
  /* USER CODE END RTOS_QUEUES */

  /* Create the thread(s) */
  /* creation of defaultTask */
  defaultTaskHandle = osThreadNew(StartDefaultTask, NULL, &defaultTask_attributes);

  /* creation of imu_acquisition */
  imu_acquisitionHandle = osThreadNew(StartIMUTask, NULL, &imu_acquisition_attributes);

  /* creation of pose_estimation */
  pose_estimationHandle = osThreadNew(StartPose, NULL, &pose_estimation_attributes);

  /* creation of uart_send */
  uart_sendHandle = osThreadNew(StartSend, NULL, &uart_send_attributes);

  /* USER CODE BEGIN RTOS_THREADS */
  /* add threads, ... */
  /* USER CODE END RTOS_THREADS */

  /* USER CODE BEGIN RTOS_EVENTS */
  /* add events, ... */
  /* USER CODE END RTOS_EVENTS */

  /* Start scheduler */
  osKernelStart();

  /* We should never get here as control is now taken by the scheduler */

  /* Infinite loop */
  /* USER CODE BEGIN WHILE */
  while (1)
  {
    /* USER CODE END WHILE */

    /* USER CODE BEGIN 3 */

  }
  /* USER CODE END 3 */
}

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
/* USER CODE BEGIN 4 */
uint32_t GetTimeUS_TIM(void)
{
    return htim2.Instance->CNT;  // 每次读取当前时间(us)
	//return 0;
}
// TIM1 定时器中断回调函数
// TIM1 timer interrupt callback function

void HAL_TIM_PeriodElapsedCallback(TIM_HandleTypeDef *htim) {

  if (htim->Instance == TIM1) {

	//HAL_Delay(1);
    // 启动 SPI1 DMA 接收
    // Start SPI1 DMA reception
	//ICM42688P_Read_FIFO_DMA();

	  icm42688_read_all(&imudata);
	  GetPose();
	  //HAL_GPIO_TogglePin(GPIOB, GPIO_PIN_4);
  }


}

void HAL_SPI_TxRxCpltCallback(SPI_HandleTypeDef *hspi) {
  if (hspi->Instance == SPI1) {
    //BaseType_t xHigherPriorityTaskWoken = pdFALSE;
    Icm_CS_HIGH();

    // 释放信号量
    //xSemaphoreGiveFromISR(xImuDataReadySemaphore, &xHigherPriorityTaskWoken);
    //portYIELD_FROM_ISR(xHigherPriorityTaskWoken);
  }
}

/* USER CODE END 4 */

/* USER CODE BEGIN Header_StartDefaultTask */
void mavlink_send_heartbeat(void) {
    mavlink_message_t msg;
    mavlink_heartbeat_t heartbeat;

    heartbeat.type = MAV_TYPE_QUADROTOR;
    heartbeat.autopilot = MAV_AUTOPILOT_ARDUPILOTMEGA;
    heartbeat.base_mode = MAV_MODE_FLAG_CUSTOM_MODE_ENABLED;
    heartbeat.custom_mode = 0;
    heartbeat.system_status = MAV_STATE_ACTIVE;
    heartbeat.mavlink_version = 3;

    mavlink_msg_heartbeat_encode(1, 1, &msg, &heartbeat);

    uint16_t len = mavlink_msg_to_send_buffer(mavlink_tx_buffer, &msg);
    HAL_UART_Transmit(&huart2, mavlink_tx_buffer, len, HAL_MAX_DELAY);
}
void SendToPC(void){
	 //HAL_UART_Transmit_DMA(&huart2, tx_data, sizeof(tx_data) - 1);
    // 定义 Mavlink 消息和状态
    mavlink_message_t msg;
    uint16_t len;

    // 创建一个 Attitude 消息
    mavlink_attitude_t attitude;

    // 填充消息字段
    attitude.time_boot_ms = HAL_GetTick(); // 使用 HAL 库获取系统启动时间（毫秒）
    attitude.roll = euler.angle.roll;                   // 滚转角（弧度）
    attitude.pitch = euler.angle.pitch;                  // 俯仰角（弧度）
    attitude.yaw = euler.angle.yaw;                    // 偏航角（弧度）


    // 将 Attitude 消息打包成 Mavlink 消息
    // 参数: system_id, component_id, &msg, &attitude
    mavlink_msg_attitude_encode(1, 1, &msg, &attitude);

    // 将 Mavlink 消息序列化到缓冲区
    len = mavlink_msg_to_send_buffer(mavlink_tx_buffer, &msg);

    // 使用 HAL_UART_Transmit 发送数据
    // 假设你使用 USART2，其句柄为 &huart2
    //HAL_UART_Transmit(&huart2, tx_data, sizeof(tx_data) - 1, HAL_MAX_DELAY);

    HAL_UART_Transmit(&huart2, mavlink_tx_buffer, len, HAL_MAX_DELAY);

}
/**
  * @brief  Function implementing the defaultTask thread.
  * @param  argument: Not used
  * @retval None
  */
/* USER CODE END Header_StartDefaultTask */
void StartDefaultTask(void *argument)
{
  /* USER CODE BEGIN 5 */
  /* Infinite loop */
  for(;;)
  {
	  //HAL_UART_Transmit_DMA(&huart2, tx_data, sizeof(tx_data) - 1);
	  mavlink_send_heartbeat();
      osDelay(10);
	  SendToPC();
      osDelay(10);

  }
  /* USER CODE END 5 */
}

/* USER CODE BEGIN Header_StartIMUTask */
/**
* @brief Function implementing the imu_acquisition thread.
* @param argument: Not used
* @retval None
*/
/* USER CODE END Header_StartIMUTask */
void StartIMUTask(void *argument)
{
  /* USER CODE BEGIN StartIMUTask */


  /* Infinite loop */
  for(;;)
  {
    osDelay(1);
  }
  /* USER CODE END StartIMUTask */
}

/* USER CODE BEGIN Header_StartPose */
void GetPose(void){
	preCNT = GetTimeUS_TIM();
		  // Acquire latest sensor data
		          const clock_t timestamp = clock(); // replace this with actual gyroscope timestamp
		          FusionVector gyroscope = {imudata.gyro_x, imudata.gyro_y, imudata.gyro_z}; // replace this with actual gyroscope data in degrees/s
		          FusionVector accelerometer = {imudata.accel_x, imudata.accel_y, imudata.accel_z}; // replace this with actual accelerometer data in g

		          // Apply calibration
		          gyroscope = FusionCalibrationInertial(gyroscope, gyroscopeMisalignment, gyroscopeSensitivity, gyroscopeOffset);
		          accelerometer = FusionCalibrationInertial(accelerometer, accelerometerMisalignment, accelerometerSensitivity, accelerometerOffset);

		          // Update gyroscope offset correction algorithm
		          gyroscope = FusionOffsetUpdate(&offset, gyroscope);

		          // Calculate delta time (in seconds) to account for gyroscope sample clock error
		          static clock_t previousTimestamp;
		          const float deltaTime = (float) (timestamp - previousTimestamp) / (float) CLOCKS_PER_SEC;
		          previousTimestamp = timestamp;

		          // Update gyroscope AHRS algorithm
		          FusionAhrsUpdateNoMagnetometer(&ahrs, gyroscope, accelerometer, 0.01);

		          // Print algorithm outputs
		          euler = FusionQuaternionToEuler(FusionAhrsGetQuaternion(&ahrs));

	        	  delCNT = GetTimeUS_TIM()-preCNT;

}
/**
* @brief Function implementing the pose_estimation thread.
* @param argument: Not used
* @retval None
*/
/* USER CODE END Header_StartPose */
void StartPose(void *argument)
{
  /* USER CODE BEGIN StartPose */




  /* Infinite loop */
  for(;;)
  {
	  osDelay(1);

  }
  /* USER CODE END StartPose */
}

/* USER CODE BEGIN Header_StartSend */
/**
* @brief Function implementing the uart_send thread.
* @param argument: Not used
* @retval None
*/
/* USER CODE END Header_StartSend */
void StartSend(void *argument)
{
  /* USER CODE BEGIN StartSend */
  /* Infinite loop */
  for(;;)
  {
    osDelay(1);
  }
  /* USER CODE END StartSend */
}

/**
  * @brief  This function is executed in case of error occurrence.
  * @retval None
  */
void Error_Handler(void)
{
  /* USER CODE BEGIN Error_Handler_Debug */
  /* User can add his own implementation to report the HAL error return state */
  __disable_irq();
  while (1)
  {
  }
  /* USER CODE END Error_Handler_Debug */
}
#ifdef USE_FULL_ASSERT
/**
  * @brief  Reports the name of the source file and the source line number
  *         where the assert_param error has occurred.
  * @param  file: pointer to the source file name
  * @param  line: assert_param error line source number
  * @retval None
  */
void assert_failed(uint8_t *file, uint32_t line)
{
  /* USER CODE BEGIN 6 */
  /* User can add his own implementation to report the file name and line number,
     ex: printf("Wrong parameters value: file %s on line %d\r\n", file, line) */
  /* USER CODE END 6 */
}
#endif /* USE_FULL_ASSERT */

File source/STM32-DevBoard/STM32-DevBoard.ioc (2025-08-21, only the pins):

Mcu.UserName=STM32F405RGTx
PA10.Signal=USART1_RX
PA13.Signal=SYS_JTMS-SWDIO
PA14.Signal=SYS_JTCK-SWCLK
PA2.GPIO_Label=USART2_TX 
PA2.Signal=USART2_TX
PA3.GPIO_Label=USART2_RX
PA3.Signal=USART2_RX
PA4.Signal=GPIO_Output
PA5.GPIO_Label=IMU_CLK
PA5.Signal=SPI1_SCK
PA6.GPIO_Label=IMU_MISO
PA6.Signal=SPI1_MISO
PA7.GPIO_Label=IMU_MOSI
PA7.Signal=SPI1_MOSI
PA9.Signal=USART1_TX
PB0.GPIO_Label=IMU_INT1
PB0.Signal=GPXTI0
PB3.Signal=SYS_JTDO-SWO
PB4.GPIO_Label=Status_LED1
PB4.Signal=GPIO_Output
PB5.GPIO_Label=Status_LED2
PB5.Signal=GPIO_Output
PC4.GPIO_Label=IMU_CS
PC4.Signal=GPIO_Output
PH0-OSC_IN.Signal=RCC_OSC_IN
PH1-OSC_OUT.Signal=RCC_OSC_OUT

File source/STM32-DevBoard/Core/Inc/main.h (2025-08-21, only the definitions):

#define USART2_TX_Pin GPIO_PIN_2
#define USART2_TX_GPIO_Port GPIOA
#define USART2_RX_Pin GPIO_PIN_3
#define USART2_RX_GPIO_Port GPIOA
#define IMU_CLK_Pin GPIO_PIN_5
#define IMU_CLK_GPIO_Port GPIOA
#define IMU_MISO_Pin GPIO_PIN_6
#define IMU_MISO_GPIO_Port GPIOA
#define IMU_MOSI_Pin GPIO_PIN_7
#define IMU_MOSI_GPIO_Port GPIOA
#define IMU_CS_Pin GPIO_PIN_4
#define IMU_CS_GPIO_Port GPIOC
#define IMU_INT1_Pin GPIO_PIN_0
#define IMU_INT1_GPIO_Port GPIOB
#define IMU_INT1_EXTI_IRQn EXTI0_IRQn
#define Status_LED1_Pin GPIO_PIN_4
#define Status_LED1_GPIO_Port GPIOB
#define Status_LED2_Pin GPIO_PIN_5
#define Status_LED2_GPIO_Port GPIOB

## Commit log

2025-06-17 Move to github
    [2169900001.stp, 2171750001.stp, 4682 Micro SD Breakout.step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]
2025-06-18 add usb and clean up
    [Connectors.kicad_sch, MX_IMU.kicad_pcb, MX_IMU.kicad_sch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]
2025-07-01 add mounting hole
    [Connectors.kicad_sch, MX_IMU.csv, MX_IMU.kicad_pcb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]
2025-07-01 Cleanup and check on JCLPCB
    [705530039.stp, Connectors.kicad_sch, MX_IMU.kicad_pcb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]
2025-07-04 Remove vias around Y200 and IMU
    [MX_IMU.kicad_pcb]
2025-07-07 add coper ground and other design
    [MX_IMU.kicad_pcb]
2025-07-08 Version for JLCPCB
    [Connectors.kicad_sch, MX_IMU.kicad_pcb, bom.csv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]
2025-08-21 Add firmware source
    [2169900001.stp, 2171750001.stp, 4682 Micro SD Breakout.step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]

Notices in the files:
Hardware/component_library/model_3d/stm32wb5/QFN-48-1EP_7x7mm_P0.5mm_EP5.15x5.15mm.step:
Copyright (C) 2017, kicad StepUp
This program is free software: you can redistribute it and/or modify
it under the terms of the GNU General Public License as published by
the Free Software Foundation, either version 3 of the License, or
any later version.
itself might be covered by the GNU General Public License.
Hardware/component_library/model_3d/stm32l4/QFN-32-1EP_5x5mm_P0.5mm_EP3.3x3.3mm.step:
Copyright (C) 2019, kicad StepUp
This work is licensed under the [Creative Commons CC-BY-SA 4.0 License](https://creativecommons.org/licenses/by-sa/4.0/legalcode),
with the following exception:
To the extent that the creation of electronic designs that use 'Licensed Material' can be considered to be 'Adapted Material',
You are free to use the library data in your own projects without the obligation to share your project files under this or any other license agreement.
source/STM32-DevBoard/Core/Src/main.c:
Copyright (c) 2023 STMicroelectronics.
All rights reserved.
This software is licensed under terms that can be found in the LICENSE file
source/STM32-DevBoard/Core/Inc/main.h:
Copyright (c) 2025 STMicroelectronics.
